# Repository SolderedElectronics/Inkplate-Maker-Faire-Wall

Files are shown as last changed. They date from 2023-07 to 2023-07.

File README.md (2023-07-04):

#  Inkplate Maker Faire Wall

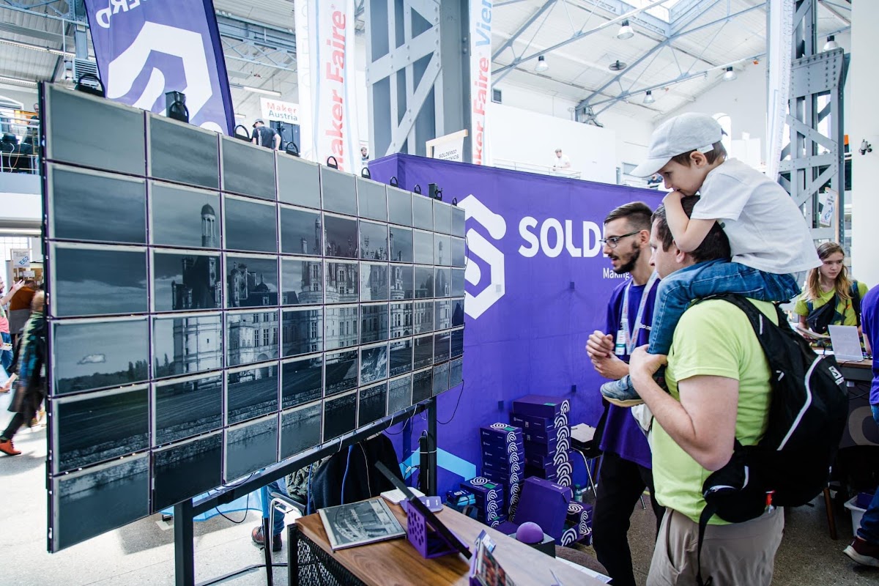
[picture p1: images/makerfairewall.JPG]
Inkplate Maker Faire Wall


As seen at Maker Faire Vienna 2023, the Inkplate Make Faire Wall is a large display made from *60* Inkplate 10's!. Yes, 60.
It's ~2.24 meters wide and ~1 meter tall. The total resolution is 13170x5630 px.

It has pre-loaded images on SD cards and changes the image at the press of a button.

Everything which is required to make it run is included in this repository. You will need:
* 60 Inkplate 10's with batteries
* The 3D printed enclosure which holds the Inkplates together
* 60 MicroSD cards (with enough space to contain all the images you want displayed)
* Enough USB Hubs to connect 60 Inkplates via serial
* A Computer (or two) to run the show (more info below)

## How it works:

### Schematic
Below is the schematic of how everything is connected:
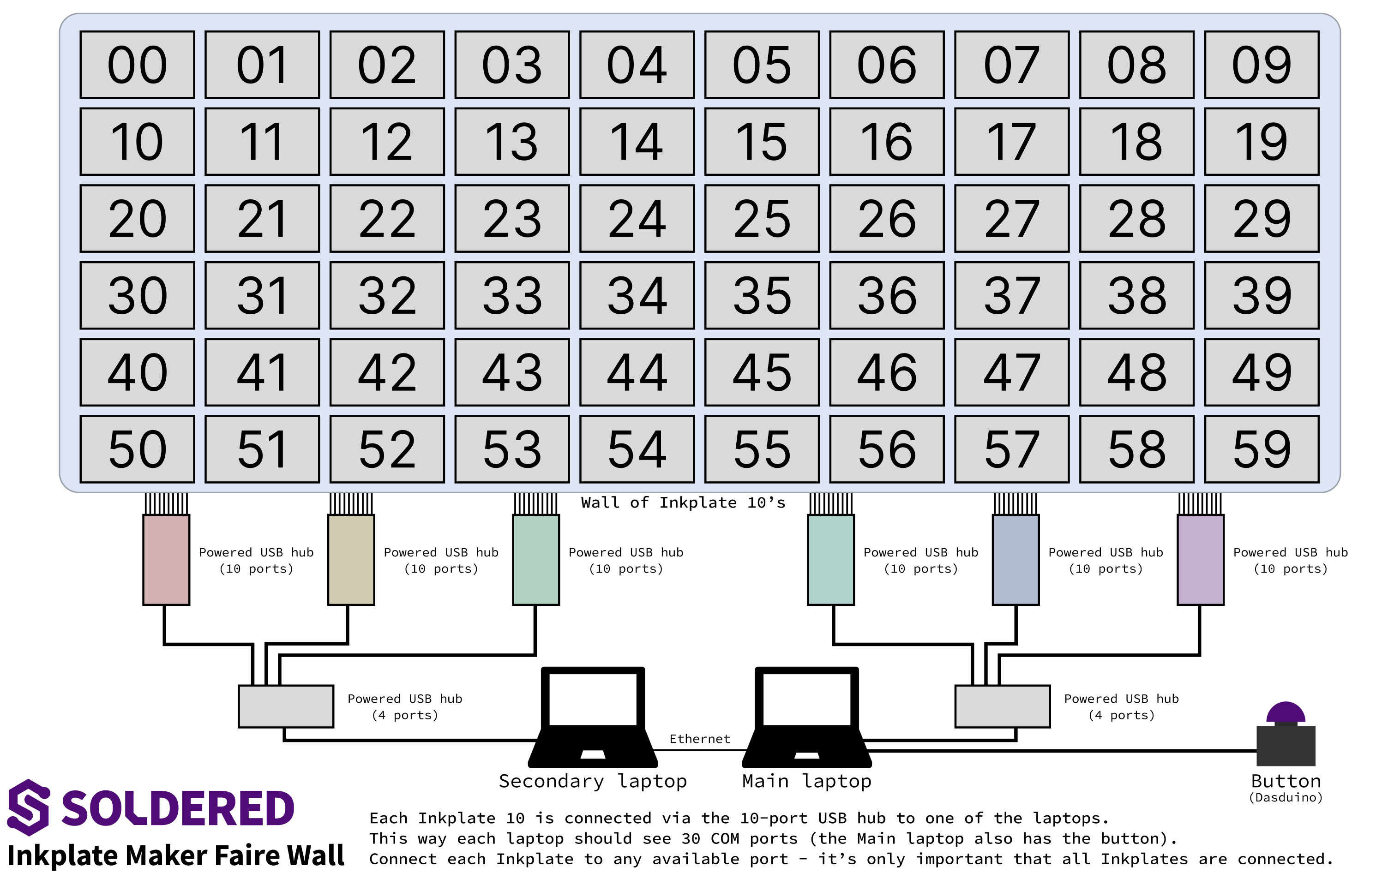
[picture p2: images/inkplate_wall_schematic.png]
Inkplate Maker Faire Wall Schematic


### The Sketch
All Inkplates are running the same sketch (inkplate_makerfaire_wall.ino). This sketch is used to recieve commands via serial to switch the operation mode and also to configure each Inkplate. The configuration process involves defining which display on the wall they represent (00, 01, 02... from left to right, top to bottom. On the bottom right is display 59). This is then stored in EEPROM. This way, each Inkplate knows the segment of the image (and thus, the filename) that it has to show. Then, sending the root filename of the image via serial to each Inkplate will trigger that image being shown on them.

Here are the different operational modes implemented, to swtich all the Inkplates to a certain mode, send the name of the operational mode over Serial.
| Operational mode name  | Description |
| --- | --- |
| OP_MODE_SLEEP  | Put all the Inkplates to sleep, useful for charging them.  |
| OP_MODE_IMAGEFRAME  | Put the inkplates into the image frame mode. While Inkplates are in this mode, sending the root filename (eg. 'car') over serial opens car_xx.jpg from the SD card, xx being the number assigned to this display over configuration. |
| OP_MODE_WAIT  | Just wait for the next command, do nothing. |
| OP_MODE_VCOM  | Goes to set the VCOM of the Inkplate. This is useful to get the best looking image.  |
| OP_MODE_RESET  | Reset the Inkplate  |

### The computers
So, why two laptops? Let's just say there are difficulties when you try to connect 60 COM ports to a Raspberry Pi or Windows PC. Theoretically this would be supported, but we ended up having to split the COM ports between two laptops - one 'main' and one 'secondary'. Each of them has 30 Inkplate 10's connected via a USB hub. The 'main' laptop also has the Button on another Serial port. The two laptops are then connected together via Ethernet for fast communication. The communication between the two laptops basically involves the first laptop telling the other 'go to the next image'.

### Batteries
Batteries are required. Inkplate 10 draws a bit more current when it's refreshing. This quickly adds up, so the USB Hubs can't provide enough power. This is why the Inkplates need to have a battery. In order for the display to work - the battery has to be charged, as it automatically compensates for the current draw when the screen is being refreshed. The best way to charge the battery is to connect everything and then send OP_MODE_SLEEP via the serial_sender.py script to put all the ESP's to sleep - allowing for the battery to be charged.

### Image files
Image files to display have to be loaded on the SD card. Crop them using the inkplate-wall-image-cropper tool included in this repo. The images to input to the tool must be exactly 13170 x 5630px, .jpg works best. To find good images search for 'gigapixel images' or use Google advanced image search, find the image you want and crop to fit using your favorite image editing program. All of the cropped image outputs from the tool need to be in the (SD Card root)/wall_img directory. So, this directory will be full of many images like 00_image1.jpg, 32_solderedLogo.jpg, 14_test.jpg, 02_image2.jpg etc. You don't need to delete images which are not for this particular display to save time, the right one will be loaded via the identifier.

### Python scripts
This is the list of Python scripts used and what they do:
| Script name  | Description |
| --- | --- |
| serial_sender.py  | Used for diagnostics and testing, sends a single line over Serial to all ports. |
| num_ports.py  | Just prints the number of ports connected via Serial to the current computer. Each Computer needs to have 30 ports connected via Serial, so this quickly checks if everything is connected well.  |
| batch_uploader.py | Uploads a pre-compiled ESP32 .bin file to all the Serial ports. Useful if something in the main sketch needs to be changed. |
| inkplate_wall_image_cropper.py  | Crops a 13170x5630 image file to 60 different files with some spacing in between. |
| main_slideshow_laptop.py  | Runs on the main laptop  |
| secondary_slideshow_laptop.py  | Runs on the second laptop  |

### The button
The button is actually a Dasduino which sends a string via Serial upon press of a button. It's running the simple push_button.ino sketch.

### 3D printed case
You can find the files for 3D printing the casing in the 'case' folder. This design enables modular connecting of Inkplate 10's side-by-side in any dimension. The practicality of this design made it possible to dissasemble the panels and transport them and also enabled us to easily repair the display as a whole.

### If you want to make this
Contact us! We'd be glad to help.

### About Soldered

soldered-logo

At Soldered, we design and manufacture a wide selection of electronic products to help you turn your ideas into acts and bring you one step closer to your final project. Our products are intented for makers and crafted in-house by our experienced team in Osijek, Croatia. We believe that sharing is a crucial element for improvement and innovation, and we work hard to stay connected with all our makers regardless of their skill or experience level. Therefore, all our products are open-source. Finally, we always have your back. If you face any problem concerning either your shopping experience or your electronics project, our team will help you deal with it, offering efficient customer service and cost-free technical support anytime. Some of those might be useful for you:

- [Web Store](https://www.soldered.com/shop)
- [Tutorials & Projects](https://soldered.com/learn)
- [Community & Technical support](https://soldered.com/community)

## Have fun!

And thank you from your fellow makers at Soldered Electronics.

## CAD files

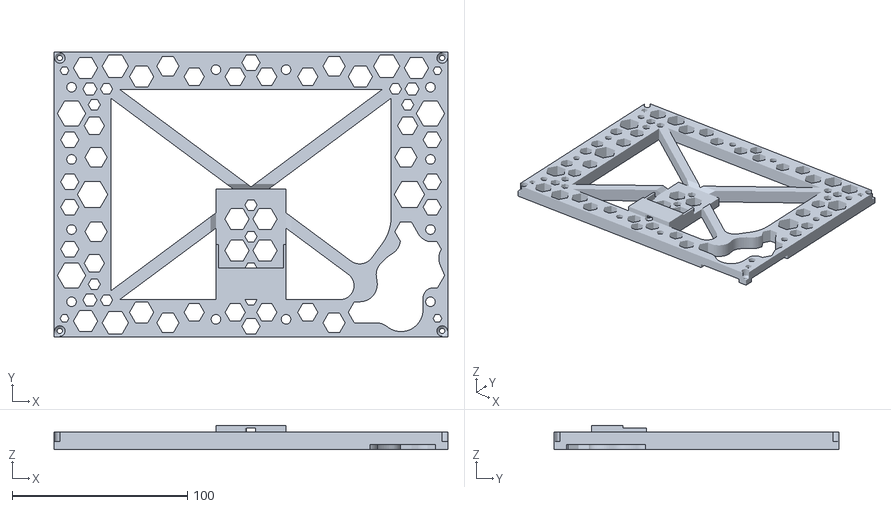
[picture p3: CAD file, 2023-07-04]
3D_print_files/holder.stl
224.8 x 162.4 x 13.8

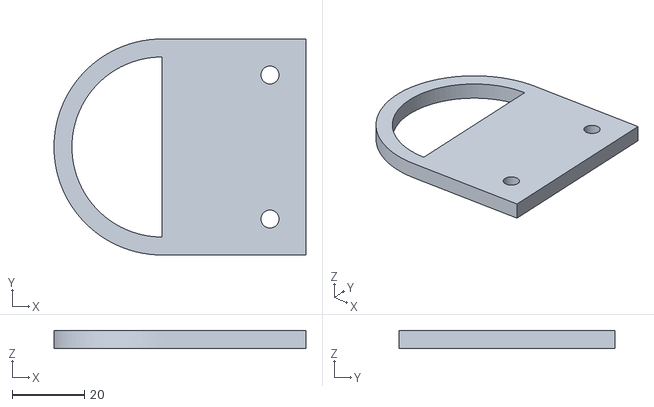
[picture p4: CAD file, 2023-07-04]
3D_print_files/link_ends.stl
70.0 x 60.0 x 5.00

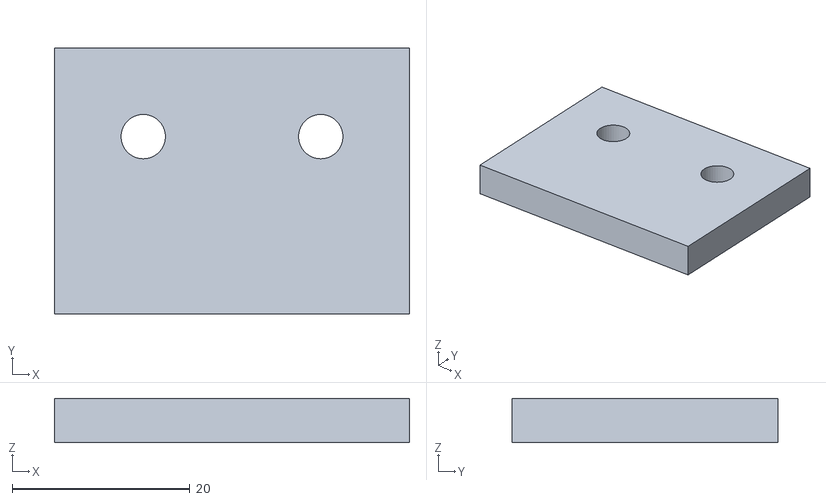
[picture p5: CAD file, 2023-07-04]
3D_print_files/link_half.stl
40.0 x 30.0 x 5.00

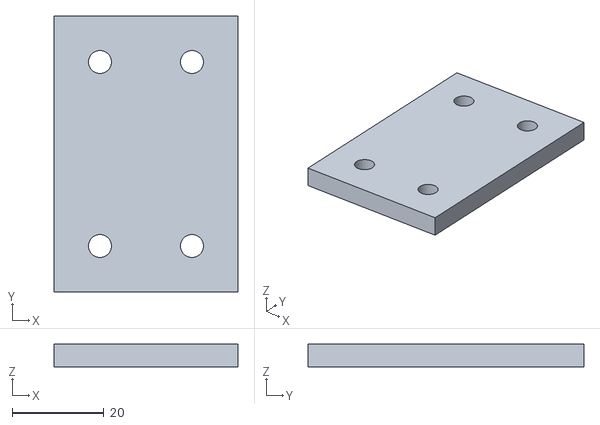
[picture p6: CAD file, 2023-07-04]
3D_print_files/link.stl
40.0 x 60.0 x 5.00

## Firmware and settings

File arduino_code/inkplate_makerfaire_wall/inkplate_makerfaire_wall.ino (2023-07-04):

/**
 **************************************************
 *
 * @file        inkplate_makerfaire_wall.ino
 * @brief       This is the main sketch for the Inkplate 10 Wall, as seen on Maker Faire in Vienna in 2023
 *
 *              Details on how it all works are in the README
 *
 *              Inkplate 10 with battery: solde.red/333247
 *
 * @authors     Robert @ soldered.com
 ***************************************************/

// Include needed libraries
#include "Inkplate.h"
#include "EEPROM.h"

#include "soldered_logo.h"

// EEPROM location where the config is written
#define WALL_CONFIG_EEPROM_ADDR 180

// Define the timeout in seconds for configuring
#define CONFIG_TIMEOUT_SECONDS 10

// Define the folder name where all the image files are located
const char *folderName = "wall_img";

// VCOM value if it gets configured:
double vcomVoltage;

// All waveforms for Inkplate 10 boards
uint8_t waveform1[8][9] = {{0, 0, 0, 0, 0, 0, 0, 1, 0}, {0, 0, 0, 2, 2, 2, 1, 1, 0}, {0, 0, 2, 1, 1, 2, 2, 1, 0}, {0, 1, 2, 2, 1, 2, 2, 1, 0}, {0, 0, 2, 1, 2, 2, 2, 1, 0}, {0, 2, 2, 2, 2, 2, 2, 1, 0}, {0, 0, 0, 0, 0, 2, 1, 2, 0}, {0, 0, 0, 2, 2, 2, 2, 2, 0}};
uint8_t waveform2[8][9] = {{0, 0, 0, 0, 0, 0, 0, 0, 0}, {0, 0, 0, 2, 1, 2, 1, 1, 0}, {0, 0, 0, 2, 2, 1, 2, 1, 0}, {0, 0, 2, 2, 1, 2, 2, 1, 0}, {0, 0, 0, 2, 1, 1, 1, 2, 0}, {0, 0, 2, 2, 2, 1, 1, 2, 0}, {0, 0, 0, 0, 0, 1, 2, 2, 0}, {0, 0, 0, 0, 2, 2, 2, 2, 0}};
uint8_t waveform3[8][9] = {{0, 3, 3, 3, 3, 3, 3, 3, 0}, {0, 1, 2, 1, 1, 2, 2, 1, 0}, {0, 2, 2, 2, 1, 2, 2, 1, 0}, {0, 0, 2, 2, 2, 2, 2, 1, 0}, {0, 3, 3, 2, 1, 1, 1, 2, 0}, {0, 3, 3, 2, 2, 1, 1, 2, 0}, {0, 2, 1, 2, 1, 2, 1, 2, 0}, {0, 3, 3, 3, 2, 2, 2, 2, 0}};
uint8_t waveform4[8][9] = {{0, 0, 0, 0, 0, 0, 0, 1, 0}, {0, 0, 0, 2, 2, 2, 1, 1, 0}, {0, 0, 2, 1, 1, 2, 2, 1, 0}, {1, 1, 2, 2, 1, 2, 2, 1, 0}, {0, 0, 2, 1, 2, 2, 2, 1, 0}, {0, 1, 2, 2, 2, 2, 2, 1, 0}, {0, 0, 0, 2, 2, 2, 1, 2, 0}, {0, 0, 0, 2, 2, 2, 2, 2, 0}};
uint8_t waveform5[8][9] = {{0, 0, 0, 0, 0, 0, 0, 1, 0}, {0, 0, 0, 2, 2, 2, 1, 1, 0}, {2, 2, 2, 1, 0, 2, 1, 0, 0}, {2, 1, 1, 2, 1, 1, 1, 2, 0}, {2, 2, 2, 1, 1, 1, 0, 2, 0}, {2, 2, 2, 1, 1, 2, 1, 2, 0}, {0, 0, 0, 0, 2, 1, 2, 2, 0}, {0, 0, 0, 0, 2, 2, 2, 2, 0}};
uint8_t *waveformList[] = {&waveform1[0][0], &waveform2[0][0], &waveform3[0][0], &waveform4[0][0], &waveform5[0][0]};

// Calculate number of possible waveforms
uint8_t waveformListSize = (sizeof(waveformList) / sizeof(uint8_t *));

// Struct for reading waveform from EEPROM memory of ESP32
struct waveformData waveformEEPROM;

// Waveform 1 is index 0
// Waveform 2 is index 1
// Waveform 3 is index 2
// Waveform 4 is index 3
// Waveform 5 is index 4
int selectedWaveform = 0;

// Select operation mode. Imageframe is thje only one really fully implemented, so we're leaving that one here.
// More to come in the future!
enum OPERATION_MODE
{
    OP_MODE_SLEEP = 0,
    OP_MODE_IMAGEFRAME = 1,
    OP_MODE_WAIT = 4,
    OP_MODE_CLEAN = 7,
    OP_MODE_VCOM = 8,
    OP_MODE_RESET = 9
};

// Set to run as image frame on launch
OPERATION_MODE currentOpMode = OP_MODE_IMAGEFRAME;

// Create object on Inkplate library and set library to work in 3bit mode
Inkplate display(INKPLATE_3BIT);
bool isCurrentlySetTo3BitMode = true;

// The display's ID (which display it is on the grid)
char displayID[2];

void setup()
{
    // For communication
    Serial.begin(115200);

    // Start EEPROM
    EEPROM.begin(512);

    // Init display
    display.begin();

    // Get the config from serial
    int enteredConfiguration = 1;
    bool confWasSet = false;
    do
    {
        confWasSet = getConfigFromSerial(&enteredConfiguration);
    } while ((enteredConfiguration < 0 || enteredConfiguration > 59) && confWasSet);
    // If out of range, repeat

    if (confWasSet)
    {
        // Write configuration to EEPROM if it was set
        Serial.println("Writing to EEPROM");
        display.pinModeInternal(IO_INT_ADDR, display.ioRegsInt, 6, INPUT_PULLUP);
        EEPROM.write(WALL_CONFIG_EEPROM_ADDR, enteredConfiguration);
        EEPROM.commit();
    }

    // Load the configuration number
    int savedConfiguration = EEPROM.read(WALL_CONFIG_EEPROM_ADDR);
    Serial.print("Saved configuration: ");
    Serial.println(savedConfiguration);

    // Get the saved configuration represented as chars (to look for filenames and other things)
    sprintf(displayID, "%02d", savedConfiguration);

    Serial.print("Your display is #");
    Serial.println(displayID);

    display.clearDisplay();
    display.display();

    delay(1000);

    // Init SD card. Display if SD card has init. properly or not.
    if (!display.sdCardInit())
    {
        display.clearDisplay();
        display.println("Can't load Sd!");
        display.display();
    }
}

// In loop, act differently according to the current set mode
void loop()
{
    switch (currentOpMode)
    {
    case OP_MODE_SLEEP:
        // Go to sleep!
        esp_deep_sleep_start();
        break;

    case OP_MODE_IMAGEFRAME:
        operationAsImageFrame();
        break;

    case OP_MODE_WAIT:
        operationWaitForInstructions();
        break;

    case OP_MODE_CLEAN:
        cleanScreen();
        break;

    case OP_MODE_VCOM:
        setVCOM();

    case OP_MODE_RESET:
        // Reset to reconfigure!
        esp_restart();
        break;
    }
}

// Prompt user to enter a config number
bool getConfigFromSerial(int *configNum)
{
    int configNumber = 1;
    char serialBuffer[50];
    unsigned long serialTimeout;

    // Printing settings
    display.setTextColor(BLACK);
    display.setTextSize(3);
    display.setCursor(10, 10);

    // Print the grid of numbers
    display.setCursor(160, 250);
    display.print("[00] [01] [02] [03] [04] [05] [06] [07] [08] [09]");
    display.setCursor(160, 300);
    display.print("[10] [11] [12] [13] [14] [15] [16] [17] [18] [19]");
    display.setCursor(160, 350);
    display.print("[20] [21] [22] [23] [24] [25] [26] [27] [28] [29]");
    display.setCursor(160, 400);
    display.print("[30] [31] [32] [33] [34] [35] [36] [37] [38] [39]");
    display.setCursor(160, 450);
    display.print("[40] [41] [42] [43] [44] [45] [46] [47] [48] [49]");
    display.setCursor(160, 500);
    display.print("[50] [51] [52] [53] [54] [55] [56] [57] [58] [59]");

    // Print the timeout info:
    display.setCursor(460, 680);
    display.print("Timeout: ");
    display.print(CONFIG_TIMEOUT_SECONDS);
    display.print("s!");

    display.setCursor(10, 715);
    // Show it
    display.display();

    // Get the config number from serial
    // This is very similar to getting VCOM
    while (true)
    {
        int i = 0;
        Serial.println("Send a two digit number which corresponds to which Inkplate this is in the grid:\n");

        serialTimeout = millis();
        while (!Serial.available())
        {
            unsigned long now = millis();
            if (now - serialTimeout > CONFIG_TIMEOUT_SECONDS * 1000)
            {
                Serial.println("No config entered, going into normal operation...");
                return false;
            }
        }
        while (Serial.available())
        {
            serialBuffer[i++] = Serial.read();
        }
        serialBuffer[i] = 0;

        if (sscanf(serialBuffer, "%d", &configNumber) == 1)
        {
            *configNum = configNumber;
            return true;
        }
    }

    Serial.println("Config enter error!");
    return false;
}

// This function runs in each of the modes, and is used to check if the reading from serial means the user wants to change the mode
bool switchMode(String input)
{
    if (input == "OP_MODE_SLEEP")
    {
        Serial.println("Going to sleep!");
        currentOpMode = OP_MODE_SLEEP;
        return true;
    }
    if (input == "OP_MODE_IMAGEFRAME")
    {
        Serial.println("Now working as Image frame!");
        currentOpMode = OP_MODE_IMAGEFRAME;
        return true;
    }
    if (input == "OP_MODE_WAIT")
    {
        currentOpMode = OP_MODE_WAIT;
        return true;
    }
    if (input == "OP_MODE_CLEAN")
    {
        Serial.println("Cleaning screen!");
        currentOpMode = OP_MODE_CLEAN;
        return true;
    }
    if (input == "OP_MODE_VCOM")
    {
        Serial.println("Setting VCOM!");
        currentOpMode = OP_MODE_VCOM;
        return true;
    }
    if (input == "OP_MODE_RESET")
    {
        Serial.println("Resetting!");
        currentOpMode = OP_MODE_RESET;
        return true;
    }
    return false;
}

// The main function which draws images from SD card to show on the Inkplate wall
void operationAsImageFrame()
{
    // Just to be sure check if we are in 3Bit mode, if not, switch to it
    if (!isCurrentlySetTo3BitMode)
    {
        display.setDisplayMode(INKPLATE_3BIT);
        isCurrentlySetTo3BitMode = true;
    }

    if (Serial.available())
    {
        // Get the input
        // In case the input was to switch the operational mode, break out of the function
        String serialInput = Serial.readString();
        if (switchMode(serialInput))
            return;

        // Construct the image path and display the image
        String imagePath;
        imagePath += "/";
        imagePath += folderName;
        imagePath += "/";
        imagePath += displayID;
        imagePath += "_";
        imagePath += serialInput;
        imagePath += ".jpg";
        Serial.println(imagePath);
        display.drawImage(imagePath, 0, 0, true, false);
        display.display();
    }
}

// Set the VCOM and waveform, works the same as in the diagnostic examples for Inkplate 10
void setVCOM()
{
    // Get the input
    // In case the input was to switch the operational mode, break out of the function
    String serialInput = Serial.readString();
    if (switchMode(serialInput))
        return;

    do
    {
        // Get VCOM voltage from serial from user
        uint8_t flag = getVCOMFromSerial(&vcomVoltage);

        // Show the user the entered VCOM voltage
        Serial.print("Entered VCOM: ");
        Serial.println(vcomVoltage);
        display.print(vcomVoltage);
        display.partialUpdate();

        if (vcomVoltage < -5.0 || vcomVoltage > 0.0)
        {
            Serial.println("VCOM out of range!");
            display.print(" VCOM out of range!");
            display.partialUpdate();
        }

    } while (vcomVoltage < -5.0 || vcomVoltage > 0.0);

    // Write VCOM to EEPROM
    display.pinModeInternal(IO_INT_ADDR, display.ioRegsInt, 6, INPUT_PULLUP);
    writeVCOMToEEPROM(vcomVoltage);
    EEPROM.commit();

    display.selectDisplayMode(INKPLATE_3BIT);

    // Select the waveform via serial
    // Write "OK" to confirm input
    int result = 1;
    do
    {
        result = getWaveformFromSerial(&selectedWaveform);
    } while (result != 0);

    // Write waveform to EEPROM
    waveformEEPROM.waveformId = INKPLATE10_WAVEFORM1 + selectedWaveform;
    memcpy(&waveformEEPROM.waveform, waveformList[selectedWaveform], sizeof(waveformEEPROM.waveform));
    waveformEEPROM.checksum = display.calculateChecksum(waveformEEPROM);
    display.burnWaveformToEEPROM(waveformEEPROM);

    Serial.println("Waveform burned to EEPROM!");
    Serial.println("Resetting...");

    currentOpMode = OP_MODE_RESET;
}

// Prompt the user to enter '1', '2', '3' od '4' via serial to select the waveform
// Returns 0 when done
int getWaveformFromSerial(int *selected)
{
    char serialBuffer[50];
    unsigned long serialTimeout;

    showGradient(*selected);

    while (true)
    {
        Serial.println("Write '1', '2', '3', '4' or '5' to select waveform.\nWrite 'OK' to confirm.");
        while (!Serial.available())
            ;

        serialTimeout = millis();
        int i = 0;
        while ((Serial.available()) && ((unsigned long)(millis() - serialTimeout) < 500))
        {
            if ((Serial.available()) && (i < 49))
            {
                serialBuffer[i++] = Serial.read();
                serialTimeout = millis();
            }
        }
        serialBuffer[i] = 0;
        if (strstr(serialBuffer, "1") != NULL)
        {
            *selected = 0;
            return 1;
        }
        else if (strstr(serialBuffer, "2") != NULL)
        {
            *selected = 1;
            return 1;
        }
        if (strstr(serialBuffer, "3") != NULL)
        {
            *selected = 2;
            return 1;
        }
        if (strstr(serialBuffer, "4") != NULL)
        {
            *selected = 3;
            return 1;
        }
        if (strstr(serialBuffer, "5") != NULL)
        {
            *selected = 4;
            return 1;
        }
        else if (strstr(serialBuffer, "OK") != NULL || strstr(serialBuffer, "ok") != NULL ||
                 strstr(serialBuffer, "Ok") != NULL || strstr(serialBuffer, "oK") != NULL)
        {
            return 0;
        }
    }

    Serial.println("Input error!");
    return 0;
}

// Prompt user to enter VCOM
double getVCOMFromSerial(double *_vcom)
{
    double vcom = 1;
    char serialBuffer[50];
    unsigned long serialTimeout;

    // Display a message on Inkplate
    display.print("\r\n- Write VCOM on UART: ");
    display.partialUpdate(0, 1);

    while (true)
    {
        Serial.println(
            "Write VCOM voltage from epaper panel.\r\nDon't forget negative (-) sign!\r\nUse dot as the decimal point. "
            "For example -1.23\n");
        while (!Serial.available())
            ;

        serialTimeout = millis();
        int i = 0;
        while ((Serial.available()) && ((unsigned long)(millis() - serialTimeout) < 500))
        {
            if ((Serial.available()) && (i < 49))
            {
                serialBuffer[i++] = Serial.read();
                serialTimeout = millis();
            }
        }
        serialBuffer[i] = 0;
        if (sscanf(serialBuffer, "%lf", &vcom) == 1)
        {
            *_vcom = vcom;
            return 1;
        }
    }

    return 0;
}

// Show gradient of waveform - for testing which one is best
void showGradient(int _selected)
{
    int w = display.width() / 8;
    int h = display.height() - 100;

    display.changeWaveform(waveformList[_selected]);

    display.fillRect(0, 725, 1200, 100, 7);

    display.setTextSize(3);
    display.setTextColor(0);
    display.setCursor(50, 740);
    display.print("Send '1', '2', '3', '4' or '5' via serial to select waveform.");
    display.setCursor(50, 780);
    display.print("Currently selected: ");
    display.print(_selected + 1); // Increment by 1 for printing
    display.print(", send 'OK' to confirm.");

    for (int i = 0; i < 8; i++)
    {
        display.fillRect(i * w, 0, w, h, i);
    }
    display.display();
}

// Show Inkplate 10 Null waveform
void writeToScreen()
{
    display.clean(1, 8);
    display.clean(0, 2);
    display.clean(2, 10);
    // delay(10);
}

// Write VCOM
void writeVCOMToEEPROM(double v)
{
    int vcom = int(abs(v) * 100);
    int vcomH = (vcom >> 8) & 1;
    int vcomL = vcom & 0xFF;
    // First, we have to power up TPS65186
    // Pull TPS65186 WAKEUP pin to High
    display.digitalWriteInternal(IO_INT_ADDR, display.ioRegsInt, 3, HIGH);

    // Pull TPS65186 PWR pin to High
    display.digitalWriteInternal(IO_INT_ADDR, display.ioRegsInt, 4, HIGH);
    delay(10);

    // Send to TPS65186 first 8 bits of VCOM
    writeReg(0x03, vcomL);

    // Send new value of register to TPS
    writeReg(0x04, vcomH);
    delay(1);

    // Program VCOM value to EEPROM
    writeReg(0x04, vcomH | (1 << 6));

    // Wait until EEPROM has been programmed
    delay(1);
    do
    {
        delay(1);
    } while (display.digitalReadInternal(IO_INT_ADDR, display.ioRegsInt, 6));

    // Clear Interrupt flag by reading INT1 register
    readReg(0x07);

    // Now, power off whole TPS
    // Pull TPS65186 WAKEUP pin to Low
    display.digitalWriteInternal(IO_INT_ADDR, display.ioRegsInt, 3, LOW);

    // Pull TPS65186 PWR pin to Low
    display.digitalWriteInternal(IO_INT_ADDR, display.ioRegsInt, 4, LOW);

    // Wait a little bit...
    delay(1000);

    // Power up TPS again
    display.digitalWriteInternal(IO_INT_ADDR, display.ioRegsInt, 3, HIGH);

    delay(10);

    // Read VCOM valuse from registers
    vcomL = readReg(0x03);
    vcomH = readReg(0x04);
    Serial.print("Vcom: ");
    Serial.println(vcom);
    Serial.print("Vcom register: ");
    Serial.println(vcomL | (vcomH << 8));

    // Trun off the TPS65186 and wait a little bit
    display.einkOff();
    delay(100);

    if (vcom != (vcomL | (vcomH << 8)))
    {
        Serial.println("\nVCOM EEPROM PROGRAMMING FAILED!\n");
    }
    else
    {
        Serial.println("\nVCOM EEPROM PROGRAMMING OK\n");
    }
}

// Low level functions for reading and writing to registers
void writeReg(uint8_t _reg, uint8_t _data)
{
    Wire.beginTransmission(0x48);
    Wire.write(_reg);
    Wire.write(_data);
    Wire.endTransmission();
}

uint8_t readReg(uint8_t _reg)
{
    Wire.beginTransmission(0x48);
    Wire.write(_reg);
    Wire.endTransmission(false);
    Wire.requestFrom(0x48, 1);
    return Wire.read();
}

// Do 5 clean cycles, in case there is some burn-in
void cleanScreen()
{
    if (Serial.available())
    {
        // Get the input
        // In case the input was to switch the operational mode, break out of the function
        String serialInput = Serial.readString();
        if (switchMode(serialInput))
            return;
    }

    int cycles = 5;

    // Clean it by writing clear sequence to the panel.
    while (cycles)
    {
        display.clean(1, 12);
        display.clean(2, 1);
        display.clean(0, 9);
        display.clean(2, 1);
        display.clean(1, 12);
        display.clean(2, 1);
        display.clean(0, 9);
        display.clean(2, 1);

        delay(5000);
        cycles--;
    }
}

// Just wait for user input, don't do anything else
// Sometimes useful
void operationWaitForInstructions()
{
    if (Serial.available())
    {
        // Get the input
        // In case the input was to switch the operational mode, break out of the function
        String serialInput = Serial.readString();
        if (switchMode(serialInput))
            return;
    }
}

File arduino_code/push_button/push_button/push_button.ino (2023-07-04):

// Push button to change the image displayed on the Inkplate wall
// Based on the RBD_Button library

#include <RBD_Timer.h>  // https://github.com/alextaujenis/RBD_Timer
#include <RBD_Button.h> // https://github.com/alextaujenis/RBD_Button

RBD::Button button(PA4);

void setup() {
  Serial.begin(115200);
}

void loop() {
  if(button.onPressed()) {
    Serial.println("NEXT");
  }
}
